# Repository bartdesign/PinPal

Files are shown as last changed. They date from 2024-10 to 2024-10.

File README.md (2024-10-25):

# PinPal
PinPal is a handheld device that acts as a controller for your iPhone. It has four hardware buttons and a DMD display. It is made specifically for the newly released VPX (Visual Pinball X) app on the Apple iOS App Store.

The VPX iOS app has built-in support for a ZeDMD display device, and I've built specific firmware for the Lilygo T-Display S3 AMOLED device. The display refresh speed is high enough for enjoyable gameplay, and there are also different scaling modes available to simulate a DMD pixel display. The ZeDMD firmware has full support for colorized DMD with the help of [Serum](https://github.com/zesinger/libserum).

### Gameplay:

VPX Gameplay (https://www.youtube.com/watch?v=CqxvdAZtwaw)

### DMD close up: 

VPX DMD (https://www.youtube.com/shorts/JCEzE09UcEo)

There are 4 different scaling methods available; this is using the 2x2 pixel mode ( this is drawn in a 4x4 black pixel block to simulate the DMD effect ).

### Pictures:








## Progress
-- Update 22-10-2024

- Changed the flipper buttons to the top of the unit; it works a lot better then the old version.
- 2 extra buttons for nudging. I plan to make a sqeeuze to nudge function in combination with the accelerometer in the future and use these buttons for magnasave.
- Added a cable guide system in the bottom plate to easily wire up the unit.
- The dmd display cutout has been changed to a bigger bezel and the mounting solution has been improved and optimized for the lilygo T-display amoled v2.0 solderless.

Todo:
- Better usb-c connector mount, need to lower it a bit and but the connector back a bit.
- In rare cases buttons get a little stuck, need to fiddle some more with tolerances

---

After weeks of tinkering, I've completed the first prototype of my portable pinball handheld device. While it still has some rough edges, it fully works as I originally envisioned. The current version is designed for the iPhone Pro Max series with a USB-C connector. Moving forward, I plan to release four versions:

iPhone 15/16 Pro Max (USB-C) — already released <br>
iPhone 15/16 Pro (USB-C)<br>
iPhone 13/14 Pro Max (Lightning)<br>
iPhone 13/14 Pro (Lightning)<br>

At the moment, I'm experimenting with different button configurations to improve comfort, as I'm not entirely satisfied with the current layout. I’ve also developed firmware for the ESP32 Zero that emulates a keyboard for the hardware buttons. In the next iteration, I’ll be converting this firmware to function as a game controller, which should resolve the issue of the on-screen keyboard interfering with gameplay.

I’ll be releasing all of my 3D printable files in both STL and STEP formats. I’m not a professional 3D modeler; so the models are not perfect :-) <br>
I encourage others to take my designs, improve upon them, and make the project better or start their own versions of this concept!

## BOM (Bill of materials)

|Description|Amount|Link|
|---|---|---|
|T-Display S3 AMOLED V2.0 Non-Soldered Pin [H713]| 1x | https://www.lilygo.cc/products/t-display-s3-amoled?variant=43506902368437 |
|ESP32-S3-Zero| 1x | https://www.waveshare.com/esp32-s3-zero.htm |
|Soft dome tactile push buttons (4PIN) version|4 buttons (buy a 20 pack) |https://aliexpress.com/item/1005005384244944.html|
|USB-C female 5 pin connector|2x|https://aliexpress.com/item/1005006260700701.html|
|Cylinder head screw M4|6x| - I ordered these(the site has all the exact dimensions): https://www.rvspaleis.nl/bouten/binnenzeskant/din-7984/din-7984-[-]-a2-[-]-m4/7984-2-4x12_1 <br> - USA Link of something equivalent: https://belmetric.com/m4x0-7-a2-stainless-din-7984-allen-socket-low-head-cap-screw/?sku=BSH4X12LOWSS |
|Sleeve Nut M4|6x| - I ordered these(the site has all the exact dimensions): https://www.rvspaleis.nl/moeren/hulsmoeren/verzonken-binnenzeskant/9062-2-4_1 <br> - USA link of something equivalent: https://belmetric.com/sleeve-nut-flat-head-stainless/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 |
|Small copper insulated wires|+- 70 cm| I cut op an old broken USB lead and recycled those wires |

## Build instructions

Stay tuned, i will document this later.

## Setup instructions

1. Install VPX from the Apple iOS store.
2. Click the cog at the right top to open the VPX Settings.
3. Change the DMD type to "ZeDMD-WiFi".
4. Fill in the IP Adress and use the default port number 3333.
5. Tap Done in the top right, load up a table and have fun!

## Thanks

I would like to thank the following people for help on this project, without them this wouldn't have been possible:

- [Jason Millard (jsm174)](https://github.com/jsm174)
- [Markus Kalkbrenner (mkalkbrenner )](https://github.com/mkalkbrenner)
- [David (zesinger)](https://github.com/zesinger)

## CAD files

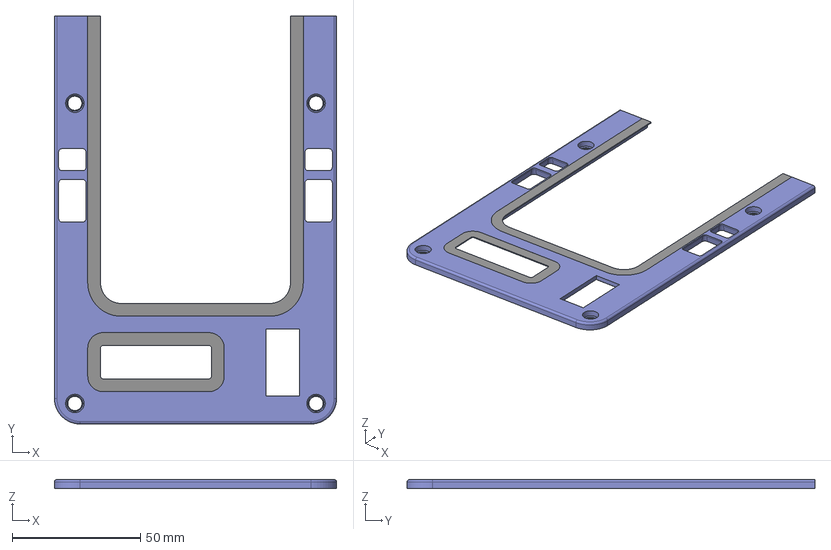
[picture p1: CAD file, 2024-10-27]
Prototype v1/iPhone Pro Max with USB-C/STEP/topplate_bottom.step
110.0 x 159.0 x 3.50 mm

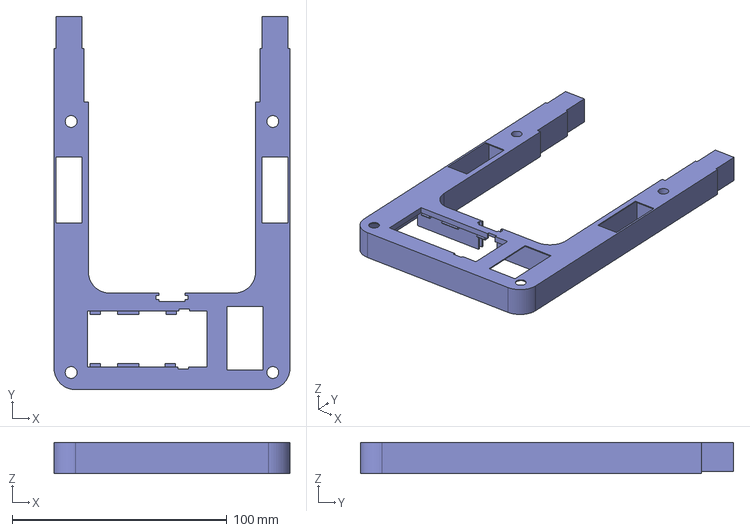
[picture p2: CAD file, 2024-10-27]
Prototype v1/iPhone Pro Max with USB-C/STEP/body_bottom.step
110.0 x 174.0 x 14.5 mm

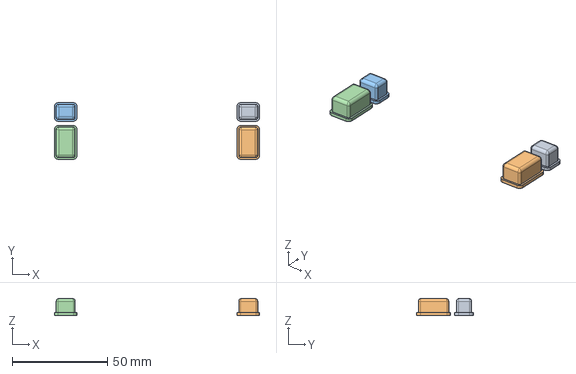
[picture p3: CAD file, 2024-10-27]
Prototype v1/iPhone Pro Max with USB-C/STEP/buttons.step
107.8 x 29.8 x 9.00 mm

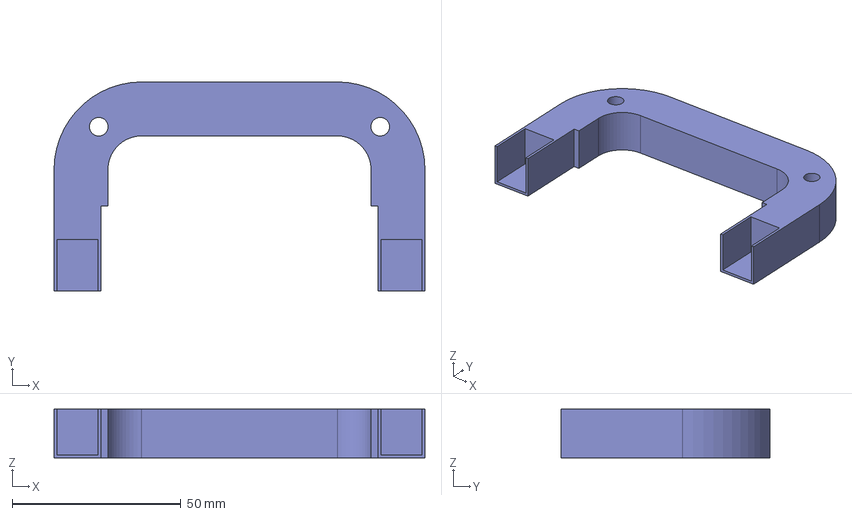
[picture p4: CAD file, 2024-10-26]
Prototype v1/iPhone Pro Max with USB-C/STEP/body_top.step
110.0 x 62.0 x 14.5 mm

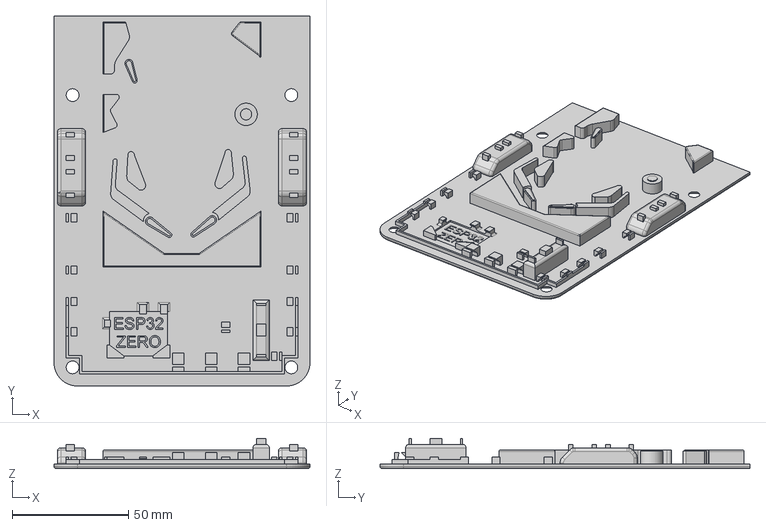
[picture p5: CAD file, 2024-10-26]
Prototype v1/iPhone Pro Max with USB-C/STEP/bottomplate_bottom.step
110.0 x 159.0 x 13.1 mm

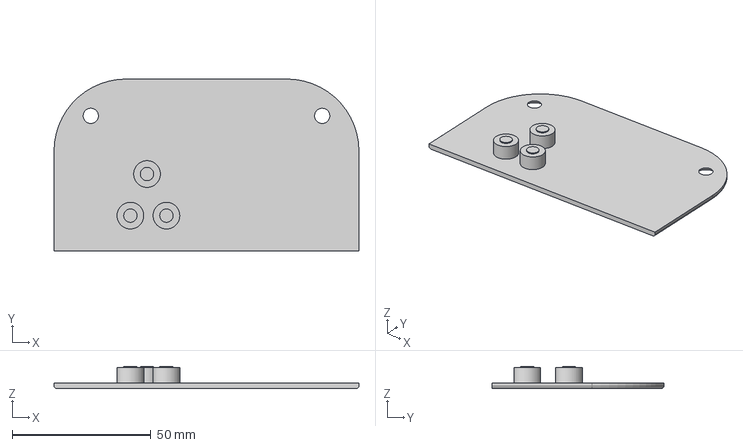
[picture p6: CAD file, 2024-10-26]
Prototype v1/iPhone Pro Max with USB-C/STEP/bottomplate_top.step
110.0 x 62.0 x 8.00 mm

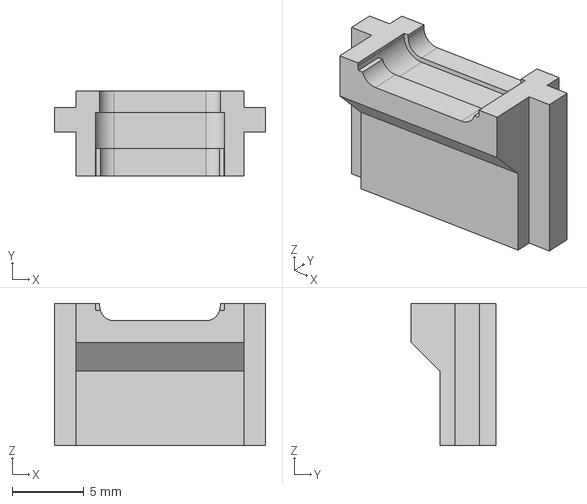
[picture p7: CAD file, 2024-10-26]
Prototype v1/iPhone Pro Max with USB-C/STEP/usb-c_bottom.step
14.7 x 5.90 x 9.90 mm

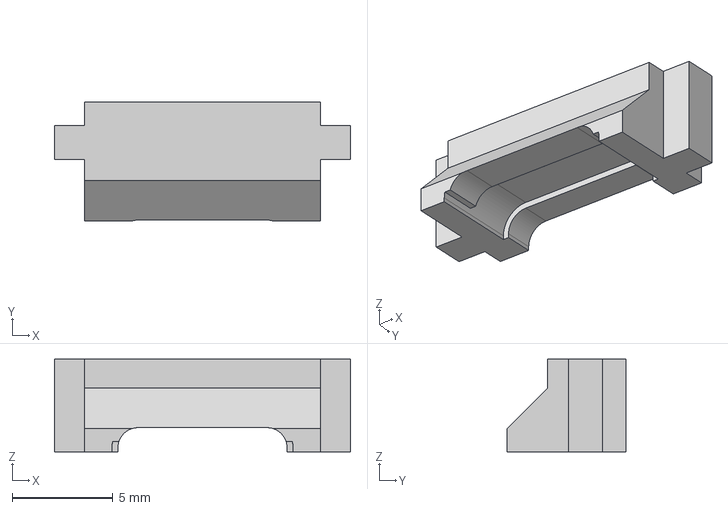
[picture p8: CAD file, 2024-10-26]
Prototype v1/iPhone Pro Max with USB-C/STEP/usb-c_top.step
14.7 x 5.90 x 4.60 mm

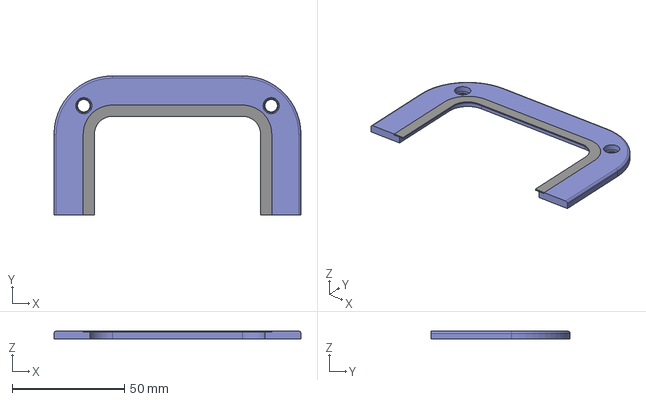
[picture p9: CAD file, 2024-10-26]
Prototype v1/iPhone Pro Max with USB-C/STEP/topplate_top.step
110.0 x 62.0 x 3.50 mm

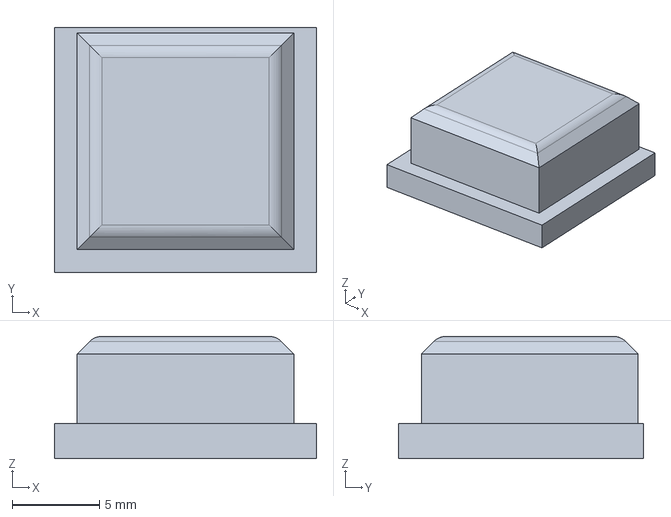
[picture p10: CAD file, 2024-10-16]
Prototype v1/iPhone Pro Max with USB-C/STEP/start button.step
15.0 x 14.0 x 7.00 mm

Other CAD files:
Prototype v1/iPhone Pro Max with USB-C/STEP/plunge button.step
Prototype v1/iPhone Pro Max with USB-C/STL/body_bottom.stl
Prototype v1/iPhone Pro Max with USB-C/STL/body_top.stl
Prototype v1/iPhone Pro Max with USB-C/STL/bottomplate_bottom.stl
Prototype v1/iPhone Pro Max with USB-C/STL/bottomplate_top.stl
Prototype v1/iPhone Pro Max with USB-C/STL/buttons.stl
Prototype v1/iPhone Pro Max with USB-C/STL/plunge button.stl
Prototype v1/iPhone Pro Max with USB-C/STL/start button.stl
Prototype v1/iPhone Pro Max with USB-C/STL/topplate_bottom.stl
Prototype v1/iPhone Pro Max with USB-C/STL/topplate_top.stl
Prototype v1/iPhone Pro Max with USB-C/STL/usb-c_bottom.stl
Prototype v1/iPhone Pro Max with USB-C/STL/usb-c_top.stl
Prototype v1/iPhone Pro Max with USB-C/pinpal.f3d

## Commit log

2024-10-16 V1 Pro Max USB-C STEP Files
    [body_button.step, body_top.step, bottomplate_top.step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]
2024-10-16 iPhone Pro Max USB-C STL Files
    [body_bottom.stl, body_top.stl, bottomplate_bottom.stl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]
2024-10-16 Upload files, changes to dir structure.
    [body_bottom.stl, body_button.step, body_top.step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]
2024-10-16 Fix stl
    [flipperbutton_mount.stl]
2024-10-16 Fix filenames.
    [body_bottom.step, portable vpin v23.stl]
2024-10-18 Update README.md
    Screw links
2024-10-22 New version with better button layout.
    [body_bottom.step, body_bottom.stl, bottomplate_bottom.stl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]
2024-10-25 Added more tolerance to the USB-C Connector fitment
    [usb-c_bottom.step, usb-c_bottom.stl, usb-c_top.step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]
2024-10-25 Changed usb-c connector tolerances for better fitment and added image of new design update.
    Updated picture to represent new design; will have to redo photo's and video's later.
2024-10-25 Changed usb-c connector tolerances for better fitment and added image of new design update.
2024-10-25 Added fusion 360 file archive.
    [pinpal.f3d]
2024-10-26 Changed some tolerances, added corners for smoother buttons and changed plunge / start button mount.
    [bottomplate_bottom.stl, buttomplate_bottom.step, pinpal.f3d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]
2024-10-26 Fixed issues after 3d printing some tests, and added playfield model instead of plastic raised bump
    [bottomplate_bottom.step, bottomplate_bottom.stl, bottomplate_top.step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]
2024-10-26 Changed body tolerance
    [body_bottom.step, body_top.step, body_top.stl]
2024-10-27 Optimized top plate and buttons to eliminate hanging buttons.
    [buttons.step, buttons.stl, topplate_bottom.step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]
2024-10-27 Changed dmd hole alignment.
    [body_bottom.step, body_bottom.stl, pinpal.f3d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]
2024-10-27 Changed DMD cutout for better fitment.
    [topplate_bottom.step, topplate_bottom.stl]
